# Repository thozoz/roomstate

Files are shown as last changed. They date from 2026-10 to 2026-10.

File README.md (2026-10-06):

# RoomState — ESP32-C3 Temperature/Humidity Monitor

A compact, battery-powered ambient temperature and humidity monitor featuring an ESP32-C3 Super Mini, DHT22 sensor, and a 0.96" SSD1306 OLED display. The monitor is housed in a custom two-part 3D-printed enclosure; build photos are shown below.

When operating on battery power, the ESP32-C3 enters light sleep between three-second sensor update cycles, allowing the OLED to retain its display buffer while reducing CPU consumption. Light sleep automatically disengages whenever a USB serial host is connected so uploading, monitoring, and debugging continue normally.

- **Board:** ESP32-C3 Super Mini (native USB-Serial/JTAG, **no** USB-UART bridge chip)
- **Sensor:** DHT22 (isolated thermal chamber)
- **Display:** 0.96" 128x64 OLED, SSD1306, I2C, address `0x3C`
- **Power & Charging:** 18650 Li-ion cell + TP4056 (with DW01A/8205A protection circuit) + KCD1 rocker switch
- **Enclosure:** Custom 3D-printed two-part desk enclosure (Bambu Lab P2S, PLA)
- **Framework:** PlatformIO + Arduino framework, flashed via esptool

---

## Physical Build & Enclosure Photos

### 1. Assembled Monitor

The assembled black enclosure with the OLED displaying temperature and humidity, the rocker switch, and the ventilation grille.

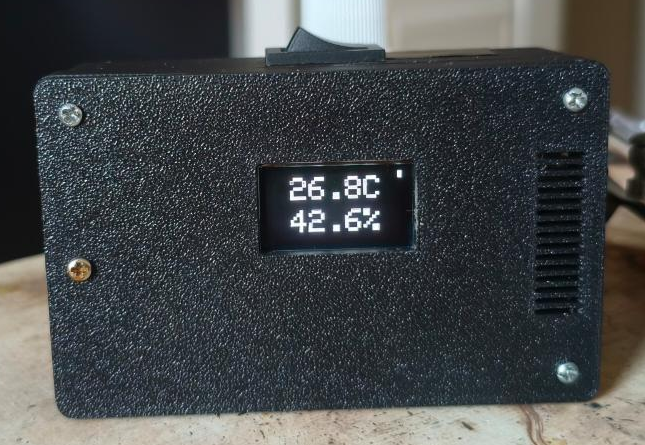
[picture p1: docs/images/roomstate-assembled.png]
Assembled RoomState monitor displaying temperature and humidity


### 2. Printed Lid

The lid before assembly, showing the OLED opening, ventilation slots, and screw holes.

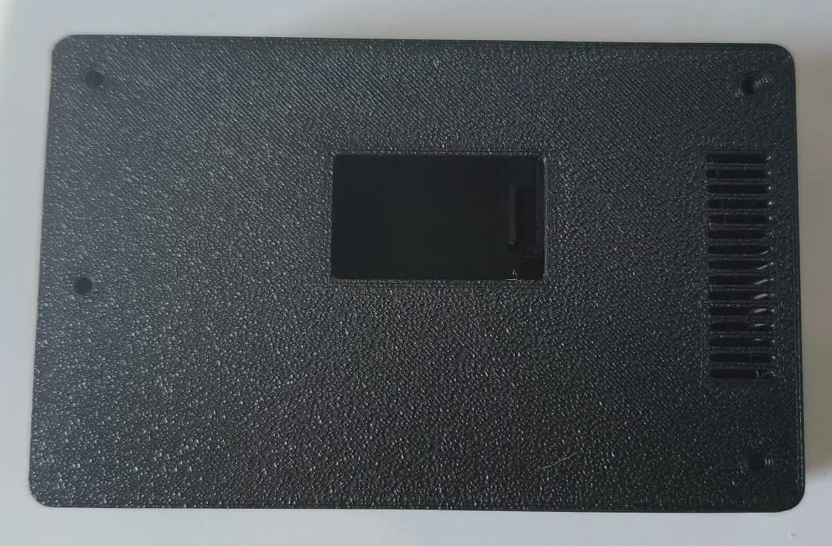
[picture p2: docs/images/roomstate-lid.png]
Black 3D-printed lid with OLED opening and ventilation slots


### 3. Base Interior

The empty base, showing the internal mounting features, compartment divider, and ventilation openings.

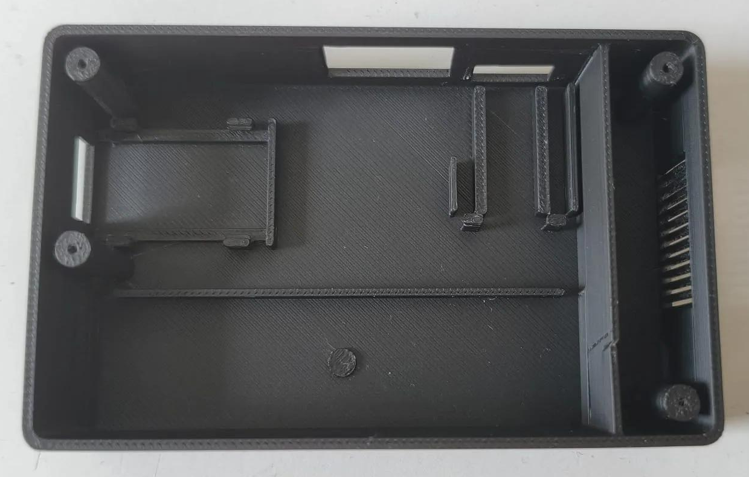
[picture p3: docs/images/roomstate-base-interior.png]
Empty 3D-printed base with mounting features and compartment divider


### 4. Internal Electronics — Angled View

The open enclosure showing the wiring, perfboard, and the OLED module mounted behind the lid.

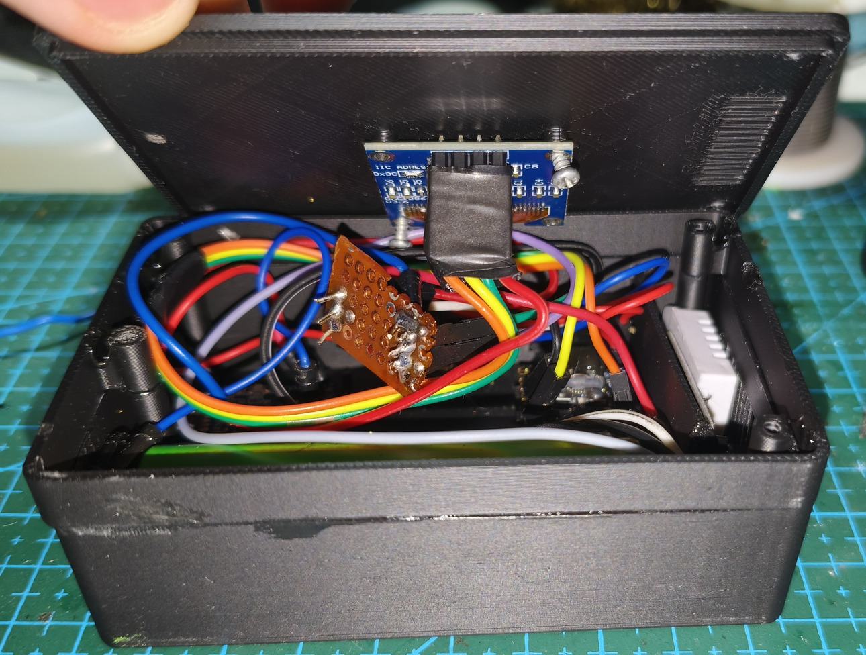
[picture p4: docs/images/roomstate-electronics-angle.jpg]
Angled view of the open RoomState enclosure, wiring, and lid-mounted OLED module


### 5. Internal Electronics — Overhead View

A closer overhead view of the 18650 cell, charging module, ESP32-C3, DHT22 sensor, and wiring.

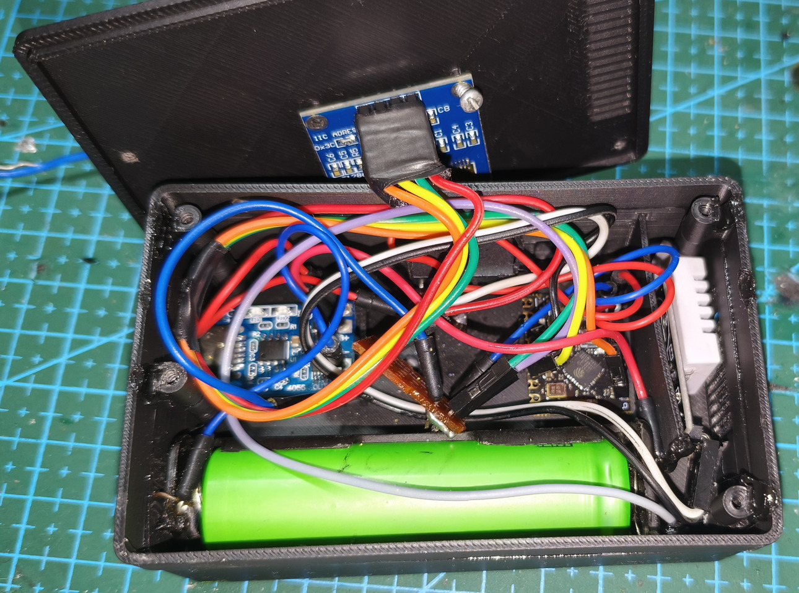
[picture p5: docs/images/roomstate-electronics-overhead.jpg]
Overhead view of the installed battery, charging module, ESP32-C3, DHT22 sensor, and wiring


---

## Pinout (Final, Verified)

| Component | ESP32-C3 Pin |
|---|---|
| DHT22 DATA | GPIO7 |
| OLED SDA | GPIO0 |
| OLED SCL | GPIO10 |
| OLED VCC / GND | **Directly from ESP 3.3V / GND** |
| DHT22 VCC / GND | **Directly from ESP 3.3V / GND** |

### Pins to Avoid

| Pin | Reason |
|---|---|
| GPIO2, GPIO8, GPIO9 | Strapping pins. If at an incorrect logic level during reset, the board will fail to boot. GPIO8 is also the onboard LED. |
| GPIO5 | Has internal board leakage on this module (behaves the same on a breadboard, internal to the ESP). |

---

## Critical Assembly Rule

> **Power modules directly from the ESP's 3.3V and GND pins, NOT from perfboard power rails.**

The longest troubleshooting session in this project stemmed from this. The display power was routed through perfboard tracks where the return ground path was inadequate. The multimeter read 3.29V at the VCC pad, yet the display was completely inoperable.

A voltmeter draws virtually no current — **it cannot detect a broken ground return path.** Voltage looks correct, yet the device is dead.

---

## Troubleshooting Guide

### Symptom → Cause Table

| Symptom | Meaning |
|---|---|
| `SDA` LOW, `SCL` clean HIGH | **Module is unpowered.** The line with a pull-up inside the module (DHT DATA, OLED SDA) gets pulled down to a dead VCC rail (~0.6V). SCL (without internal pull-up) stays clean HIGH via the ESP pull-up. This distinction is the most reliable clue. |
| Both lines LOW | Dead bus: wire shorted to GND, or a slave device is hung mid-transfer. |
| Lines clean HIGH, but no ACK | Signal is not reaching display (cold solder joint / broken wire), or SDA/SCL swapped. |
| Display freezes on last frame | ESP continues running but I2C writes fail. SSD1306 retains image in its internal GDDRAM. If the display had died completely, the screen would be blank. |
| `OLED init duration: 12003 ms` | 12 × 1000ms timeout. Bus completely dead. `display.begin()` still returns "true" — **it does not verify ACK**, do not trust its return value. |

### Software Pin Health Check

Drive the pin HIGH push-pull, then release it to internal pull-up (~45kΩ) only:

| Driven | Pull-up | Result |
|---|---|---|
| 1 | 1 | **Clean** |
| 1 | 0 | **Resistive leakage** (a few kΩ) — continuity buzzer stays silent, but pin fails to stay HIGH |
| 0 | 0 | **Hard short circuit** |

Timing is critical: after enabling pull-up, wait at least a few milliseconds. Sampling within microseconds reads LOW before the line has finished rising.

### Why Multimeters Can Mislead

- **Continuity buzzers only sound below ~50Ω.** A 6kΩ leakage pulls a logic pin LOW, but the buzzer stays silent. "No buzzer" does not mean no short.
- **Never perform continuity tests while powered.** Capacitors charging cause brief beeps, giving false positives.
- **TP4056 body diode.** Even when protection MOSFETs are off, current flows in one direction through the body diode (buzzer sounds) — yet there is no true operational ground path.
- **Voltmeters cannot see open grounds.** Correct voltage reads at VCC, but device still does not work.

### The TP4056 Grounding Trap

On protected TP4056 modules, MOSFETs sit **directly on the GND return path** (between B− and OUT−). **If no battery is connected, OUT− is disconnected.** If testing without a battery, do not establish common ground through the TP4056.

Proper wiring:
- TP4056 `B+` / `B−` → Battery
- TP4056 `OUT+` → ESP **5V** pin (never 3.3V pin — raw battery voltage reaches 4.2V)
- TP4056 `OUT−` → ESP GND
- Other modules' power → **ESP 3.3V / GND pins**, not TP4056

---

## Software Pitfalls

### 1. USB CDC Flags Are Required

The Super Mini lacks a dedicated USB-to-UART bridge chip. Without these flags, `Serial` outputs to physical UART0 pins (GPIO20/21) rather than the native USB port — you will not see a single line in terminal:

```ini
build_flags =
    -D ARDUINO_USB_MODE=1
    -D ARDUINO_USB_CDC_ON_BOOT=1
```

`ARDUINO_USB_CDC_ON_BOOT` defaults to 0. ESP32-C3 lacks full USB-OTG, only having USB-Serial/JTAG — correct mode is `ARDUINO_USB_MODE=1`.

### 2. `display.begin()` Does Not Verify ACK

It returns `true` even with no display connected, locking execution for ~12 seconds timing out on each command. Solution: verify device presence first via bit-bang probe before initializing.

### 3. Wire Peripheral Hangs on Faulty Bus

`Wire.setTimeOut()` does not cover every condition. If SCL cannot rise, `Wire.endTransmission()` can block indefinitely. Therefore:
- `Wire.begin()` is **never called** until the display is detected
- Device presence is verified via bit-bang I2C (deterministic timing, never blocks)

### 4. `Wire.end()` + `Wire.begin()` Loops Crash the Core

Do not call this pair repeatedly for periodic reconnection. Keep Wire uninitialized and use bit-bang probing instead.

### 5. Do Not Call `pinMode()` on I2C Pins While Wire Is Active

In arduino-esp32, this can break GPIO matrix routing and disconnect Wire entirely. Wire must be inactive during bit-bang operations.

### 6. 400 kHz Requires External Pull-ups

Adafruit_SSD1306 defaults bus speed to 400 kHz. Without external pull-ups, only the ESP's ~45kΩ internal pull-ups remain, and signal edges cannot rise fast enough. Reduce to 100 kHz:

```cpp
Adafruit_SSD1306 display(SCREEN_WIDTH, SCREEN_HEIGHT, &Wire, OLED_RESET, 100000UL, 100000UL);
```

Permanent solution: 4.7kΩ resistors from SDA and SCL to 3.3V. **However, if there is kΩ-range leakage on the line, even external pull-ups will not save it** — 6kΩ leakage with 4.7kΩ pull-up only reaches ~1.85V, well below the HIGH logic threshold.

### 7. Boot-time Serial Output Is Dropped

Data sent before the USB-CDC host connects is lost. Rather than printing diagnostics once in `setup()`, include recurring status lines inside `loop()`.

### 8. DTR/RTS When Connecting to Serial Port

- **DTR=1, RTS=0** → Normal read mode (HWCDC only sends output once host indicates connection)
- **DTR=1, RTS=1** → Board enters download mode and stays halted, producing no output

---

## Physical Assembly Notes

- Do not route signal and power through perfboard copper tracks. Run wires **directly to ESP pins**, using the perfboard purely as a mechanical carrier.
- Do not solder the ESP directly; **use pin headers** — if module replacement is needed, the entire board won't need rebuilding.
- **Use solid core wire.** A single stray strand from stranded wire reaching an adjacent pad is invisible, won't trigger continuity buzzers, yet causes a few kΩ of leakage.
- Clean after every solder operation with **isopropyl alcohol** (IPA, 90%+). Flux residue produces leakage in the exact kΩ range.
- **Avoid oxidant creams / hydrogen peroxide.** Creams leave conductive, hygroscopic films; peroxide oxidizes copper.
- Disconnect board power before swapping wires.
- Keep the ESP antenna keepout zone (opposite side of USB-C) clear of copper and wiring.

---

## Useful Commands

Find the device port with `pio device list`. Replace `COMx` below with your port (for example, `COM4` on Windows or `/dev/ttyACM0` on Linux). PlatformIO upload discovers the port automatically.

```bash
# Build and upload
pio run -t upload

# Reset chip (if stuck in download mode)
python -m esptool --port COMx --after hard-reset chip-id

# Full flash erase
python -m esptool --port COMx erase_flash
```

Reading serial output with PowerShell (more deterministic than `pio device monitor` — manual DTR/RTS control):

```powershell
$p = New-Object System.IO.Ports.SerialPort COMx,115200,None,8,one
$p.Open(); $p.DtrEnable=$true; $p.RtsEnable=$false
Start-Sleep -Milliseconds 5000
$p.ReadExisting(); $p.Close()
```

---

## Files

| Path | Description |
|---|---|
| `src/main.cpp` | Main firmware |
| `platformio.ini` | Board definition, USB CDC flags, libraries |
| `ENCLOSURE.md` | 3D-printed enclosure design and dimension specifications |
| `enclosure/` | 3D model exports (Base.stl, Lid.stl, STEP assemblies) |

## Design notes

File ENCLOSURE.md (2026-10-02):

# Enclosure Design

3D-printed two-part enclosure for RoomState (ESP32-C3 temperature/humidity monitor).
Modelled in Fusion 360 via the Fusion MCP server. This document tracks the design as it evolves;
sections marked **TBD** are filled in as components get measured.

## Print Target

- Printer: Bambu Lab P2S
- Material: PLA
- Goal: fast print, minimal plastic. No supports needed for either part.
- Clearance on all mating/seating surfaces: 0.15–0.2 mm

## Overall Structure

| Item | Value |
|---|---|
| Outer size | 93.2 × 58.2 × 25.6 mm |
| Inner cavity | 90 × 55 × 22 mm |
| Wall / floor | 1.6 mm (4 perimeters at 0.4 mm, no infill needed) |
| Lid | 2 mm plate + 1.5 mm inner lip, 0.2 mm clearance |
| Corners | outer R3, inner cavity R1.5, lid lip R1.3 |
| Fastening | 4 bosses, M2 self-tapping. Boss Ø5, pilot hole Ø1.6, lid through-hole Ø2.2 |
| Plastic | Base 22.2 cm³, Lid 10.4 cm³ (solid volume) |
| Orientation | Desk-clock style: screen faces up on the lid, USB-C and sensor grille on side walls |

Coordinate convention (used in all scripts): X = length, Y = width, Z = height. The inner cavity is fixed at X 2–92, Y 2–57, Z 2–24 and
every component position below is in these absolute coordinates; the outer shell is 1.6 mm outside that (0.4–93.6 / 0.4–58.6 / floor from 0.4). Units in Fusion API are cm; all scripts use a `MM = 0.1` helper.

The model is generated by Fusion API scripts (via the Fusion MCP server), not driven by user parameters. Changing a dimension means
editing the script values and regenerating the Base/Lid components; all component models (OLED, ESP32, DHT22 STEP files) stay in place.

## Internal Layout (top view, X left → right)

```
 X=0                                                   X=94
 +---------------------------------------------------------+
 |  DHT22    |                                    TP4056   |  <- Y high (back)
 |  compart- |  [ 18650 battery cradle, along X ]          |
 |  ment     |                                             |
 |  (grille  |                                             |
 |  on left  |   ESP32-C3         OLED (on lid,            |
 |  wall)    |   (floor)          window above)   USB-C -> |  <- Y low (front)
 +-----------+---------------------------------------------+
             ^ divider wall X=14
```

| Component | Position (mm, absolute) | Notes |
|---|---|---|
| DHT22 | PCB vertical at X 11.4–13, Y 22–50; sensor body Y 18–38 with mesh facing the X=0 wall | Own compartment, isolated from heat sources |
| Divider wall | X 14–15.2, full width, Z 2–22.3 (stops under the lid lip) | 8 × 6 mm cable notch at floor, Y 46–54 |
| ESP32-C3 SuperMini | On 3.5 mm rails, X 17–35, Y 2.5–25, USB-C toward the front wall | Headers pointing up |
| Rocker switch | Front wall, X 36–55.2 | Snap-in, body inside to Y 14 |
| OLED 0.96" | Mounted under the lid, board centre (45, 21), pins toward +Y | See OLED section |
| TP4056 USB-C | On 2 mm rails, X 64.5–91.5, Y 10–28 | Connector face recessed 1.1 mm inside the X=94 wall |
| 18650 in cut holder | Along X, holder X 16.5–91.5, Y 37–57 | Peg + rail + end stops, against the back wall |

Heat separation: TP4056 (charging heat) is ~55 mm from the DHT22, ESP32 ~16 mm, plus the divider.
Firmware runs WiFi/BLE off at 80 MHz so the ESP32 itself is negligible. Expect +1–2 °C drift on the
DHT22 while charging; mitigations under consideration: lid vents over TP4056, reading CHRG pin to
flag/offset readings, dropping charge current to 500 mA (R_PROG 1.2k → 2.4k).

## Cutouts and Features

### Base
- **DHT22 grille** (X=0 wall): 12 vertical slots, 0.9 mm wide, 1.9 mm pitch, Y 17–39, Z 3.2–17.3 — directly over the sensor mesh.
- **USB-C port, TP4056** (X=94 wall): 12.5 × 7.3 mm, Y 12.75–25.25, Z 3.7–11. Sized for the plug overmold (~12 × 6.5) since the receptacle face is recessed 1.1 mm.
- **USB-C port, ESP32 debug/programming** (Y=0 wall): 12.5 × 7.3 mm, X 19.75–32.25, Z 4.45–11.75. Same reasoning. Optional — can be left out of the print if not wanted.
- **Rocker switch cutout** (Y=0 wall): 19.2 × 13.2 mm, X 36–55.2, Z 6.4–19.6.
- **Board retention (snap-fit clips)**: vertical posts 1.2 mm thick outside the board edge, with a 0.6 × 0.8 mm hook overhanging the board top (+0.2 clearance). Press the board down, the post flexes, the hook holds it. No screws.
  - TP4056: 2 clips on each long edge (X 67–71 and 85–89, at Y 8.8 and 28), rear stop rib at X 63.3–64.5. Front is located by the USB-C in its cutout.
  - ESP32: long edges carry the headers, so clips sit on the rear edge (Y 25–26.2) at X 18–21 and 31–34, either side of the antenna. Side guides at X 15.9–17 (Y 3–24) and X 35–35.9 (Y 15–24, short to clear the rocker body). Front located by the USB-C.
- **Battery holder locating features**: Ø4.6 × 0.9 peg at (52.8, 47) (flush with the holder floor so the cell never touches it); rail X 18.3–87.3, Y 35.8–37, 5 mm tall; end stops X 14–15.3 (merged with the divider) and 90.3–92, 5 mm tall.
- **Screw bosses**: (6.2, 6.2), (87.8, 6.2), (6.2, 52.8), (87.8, 32). Three corners plus one mid-wall on the right (the corner spot is taken by the battery holder). Pilot hole 8 mm deep.

### Lid
- **OLED window**: 26 × 15.3 mm at X 32–58, Y 15.5–30.8 (4.2–19.5 mm below the pin edge). On this module the visible area starts right at the glass edge nearest the pins and runs 15 mm; the black flex zone is at the far end of the glass.
- **OLED bosses**: 4 × Ø3.8, 2 mm standoff, Ø1.5 pilot hole, at (33.5, 9.75), (56.5, 9.75), (33.5, 32.95), (56.5, 32.95).
- **Chimney vents** over DHT22 compartment: same slot pattern as the grille, X 4–12. Air enters via side grille, exits through lid.
- **Screw holes**: Ø2.2 through, at corner boss positions.

## Components

### OLED 0.96" SSD1306, 4-pin I2C, white — DONE (real STEP model)
Ruler measurements were inconsistent, so the component is now the community STEP model
`OLED_27x27.step` (KiCad library, github.com/louiscklaw/kicad_library), which matched every
measurement that could be trusted. Dimensions from the model, all "p" values measured from the pin edge:

| Dim | Value |
|---|---|
| Board | 27.3 × 27.3 mm, 1 mm thick |
| Mounting holes | 4 × Ø2.1 slots, centres 2.05 mm from the pin edge and from the far edge (Y spacing 23.2). In X the slots run 18.7–22.7 mm apart; **the actual board has round holes at the outer end**, so bosses sit 23.0 apart (first print had them at the slot middle, 20.7 — wrong, lid reprinted). |
| Glass | 27 × 19 × 1 mm, p = 4.15 … 23.15 |
| Visible / lit | visible area p ≈ 4.2 … 19.5 (starts at the pin-side glass edge, 15 mm long); flex/black zone p 19.5 … 23.15 |
| Pins | 4 × 2.54 header on the pin edge, pointing down (away from the glass), 9 mm long |

Placement: board centre X = 45, pin edge at Y = 35 (pins toward the battery side), board top at Z = 22, glass top at Z = 23 (1 mm below the lid underside).

### DHT22 breakout, 3-pin — DONE (measured + STEP sensor) — **sensor on hand is dead** (solder ball inside, reads 90–114 °C); replacement pending, same module type keeps the box unchanged. AHT20/SHT31 (I2C) would also fit and is the better sensor.
| Dim | Value |
|---|---|
| PCB | 28 × 13 × 1.6 mm, 3-pin header on one short edge |
| Sensor body | 15.1 × 20 × 7.7 mm (STEP `DHT22.stp`, TrailCurrent KiCad lib), plus 5.1 mm mounting tab at the far end → 25.2 total (measured 26) |
| Sensor position | body starts 12 mm from the pin edge, lies flat on the PCB, overhangs the far PCB edge by ~9 mm (total module length ~37) |
| Mesh area | ~20 × 14 mm on the face away from the PCB |

Placement: PCB stands vertical, parallel to the X=0 wall, at X 11.4–13, Y 22–50, Z 3.25–16.25.
Sensor body Y 18–38, Z 2.2–17.3, mesh face at X 3.7 (1.7 mm from the wall). Header at Y 50, pins toward +Y,
next to the cable notch. Module sits loose between wall and divider (2.7 mm play in X); no clips yet.

### TP4056 USB-C charger (with DW01A/8205A protection) — DONE (measured)
Two variants were available (27 × 18 and 19 × 15); the larger one is used — more copper, runs cooler, and there is room.

| Dim | Value |
|---|---|
| Board | 27 × 18 × 1.0 mm |
| USB-C | protrudes 1.4 mm past the board edge; total height board underside → connector top = 5 mm; receptacle ~9 × 3.3 |
| Pads | B+/B−/OUT+/OUT− on the edge opposite the USB-C |

Placement: board X 64.5–91.5, Y 10–28, on two 2 mm rails (Z 2–4) so the port cutout stays above the floor.
Board edge sits 0.5 mm back from the inner wall; USB-C face ends at X 92.9, i.e. 0.7 mm inside the outer surface (does not stick out).

### ESP32-C3 SuperMini — DONE (real STEP model)
STEP from github.com/mithro/esp32-to-433mhz (`esp32-c3-supermini.step`), matches the measured 18 × 22.5 board.

| Dim | Value |
|---|---|
| Board | 18 × 22.5 × 1.0 mm |
| USB-C | on a short edge, protrudes 1.5 mm, top at 4.2 mm above the board underside |
| Headers | 2 × 8 pins, 2.54 mm, along the long edges, **soldered pointing up** (decided). Pin stubs under the board ~2 mm → board sits on 3.5 mm rails. Pins top out at Z 11.6. |

Placement: board X 17–35, Y 2.5–25, board underside at Z 5.5 on two 3.5 mm rails at X 20–22 and 30–32 (inboard of the header rows). USB-C faces the front wall (Y=0),
face at Y 1.0 → 0.6 mm inside the outer surface (wall is now 1.6). (Moved 14 mm left from the first layout to make room for the rocker switch.) Pins used by firmware: GPIO7 (DHT data), GPIO0 (SDA), GPIO10 (SCL).

### 18650 Li-ion cell, 1200 mAh, in a cut-down spring holder — DONE (measured)
Cell Ø18 × 65 mm (the cell on hand is an 18650, not the 14500 first planned).
Runtime at ~35–40 mA (ESP32-C3 @ 80 MHz, WiFi off, OLED on, DHT22): ~30 h. Light-sleep between reads would stretch that to ~10 days — firmware task, later.

Holder: a 2×18650 spring holder cut down the middle to a single slot. One side keeps the holder's centre wall, the other side is open and rests against the box's back wall.

| Dim | Value |
|---|---|
| Holder (after cut) | 75 × 20 × 19 mm, ~1 mm floor |
| Floor hole | Ø5, centred (~38 mm from the end) |
| Solder tabs | at both ends — bend them inward/upward before fitting, there is no room past the holder ends |

Placement: X 15.3–90.3, Y 37–57 (open side to the back wall), Z 2–21. Held by: a Ø4.6 × 2.5 peg on the floor into the holder hole, a 1.2 mm rail along the inner side (Y 35.8–37, 5 mm tall), 5 mm end stops at X 15.3 and 91.5, and the back wall. No screws. Cell centre Y 47.5, Z 12; cell top Z 21.

Consequence: the back-right corner boss would collide with the holder, so it moved to (87.8, 32) — between the TP4056 and the holder. Lid hole pattern is asymmetric now.

### Power switch — DONE (KCD1 rocker, standard dims assumed)
Two options on hand: a KCD1-style rocker (~21 × 15 flange) and an SS12D00 mini slide. Rocker chosen: snap-in panel mount,
no screws or glue, works with a 2 mm wall. Rated 10 A, irrelevant at 40 mA.

| Dim | Value (standard KCD1-101, verify) |
|---|---|
| Flange | 21 × 15 mm, ~2 mm proud of the wall |
| Body behind flange | 19 × 13 mm, ~14 mm deep, then 2 pins ~6 mm |
| Panel cutout | 19.2 × 13.2 mm |

Location: front wall (Y=0), cutout X 36–55.2, Z 6.4–19.6 (centre X 45.6, Z 13). Body reaches inside to Y 14, pins to Y 20 — clear of the ESP32 (moved to X 17–35), TP4056 (X 64.5+) and the OLED (Z 21+).

## Wiring

Soldered connections (no Dupont — loosens inside a closed box). 24–26 AWG, 5–8 cm runs, heat-shrink on every joint.

| From | To |
|---|---|
| TP4056 OUT+ | rocker switch |
| rocker switch | ESP32 5V |
| TP4056 OUT− | ESP32 GND |
| TP4056 B+ / B− | holder tabs + / − |
| OLED VCC / GND / SDA / SCL | ESP32 3V3 / GND / GPIO0 / GPIO10 |
| DHT22 VCC / GND / DATA | ESP32 3V3 / GND / GPIO7 |

Note: TP4056 OUT is battery voltage (3.0–4.2 V) into the SuperMini 5V pin (regulator input). Works, but marginal at low charge.

**Backfeed / power switch:** the SuperMini's own USB-C connects VBUS straight to the 5V pin, so plugging the ESP32 USB while the battery is wired to the same pin would push 5 V back into TP4056 OUT+ and the cell. Solution chosen: a slide switch in series **TP4056 OUT+ → switch → ESP32 5V**. Switch off = battery fully disconnected from the ESP32, USB debug is safe, no diode needed. Charging via the TP4056 port works regardless of switch position (B+/B− path is not switched). Switch: KCD1 rocker on the front wall, right of the ESP32 USB-C.

## Open Decisions

- [ ] Verify the rocker switch flange/cutout against the actual part (19.2 × 13.2 assumed)
- [ ] Battery holder: confirm 75 × 20 × 19 and hole position after cutting
- [ ] Extra lid vents over TP4056 (only if charging drift turns out to matter)
- [ ] Firmware: light sleep to stretch battery life; optional CHRG-pin "charging" indicator

## Status

- [x] Box shell, lid, bosses, lip — 1.6 mm walls, R3 corners
- [x] OLED: real STEP model, window + bosses
- [x] DHT22: measured PCB + STEP sensor, side grille + lid chimney + divider
- [x] TP4056: measured, rails, USB-C cutout
- [x] ESP32-C3 SuperMini: real STEP model, headers up, rails, front USB-C cutout
- [x] 18650 in cut-down spring holder, peg/rail/stops
- [x] KCD1 rocker switch cutout, front wall
- [x] Snap-fit clips retain the TP4056 and ESP32 (no screws, no glue)
- [x] Interference check: 0 collisions between box, lid and all components
- [x] Exported: `enclosure/Base.stl` (as modelled), `enclosure/Lid.stl` (already flipped, flat face down — no rotation needed in the slicer), `enclosure/RoomState_enclosure.step` (full assembly incl. components)
- [ ] Print test fit (Base open side up, Lid top face down — no supports)
- [ ] Adjust after test fit

## Print Notes

- Base: print as modelled (open side up). Overhangs: USB-C/rocker cutouts are ≤ 19 mm bridges, fine for PLA.
- Lid: `Lid.stl` is exported already flipped — outer face on the bed, bosses and lip up. The OLED window and vent slots print as holes.
- 4 perimeters / 0.4 nozzle give solid 1.6 mm walls; 3–4 top/bottom layers; infill irrelevant.
- M2 × 6 self-tapping screws for the lid (4×) and the OLED (4×).

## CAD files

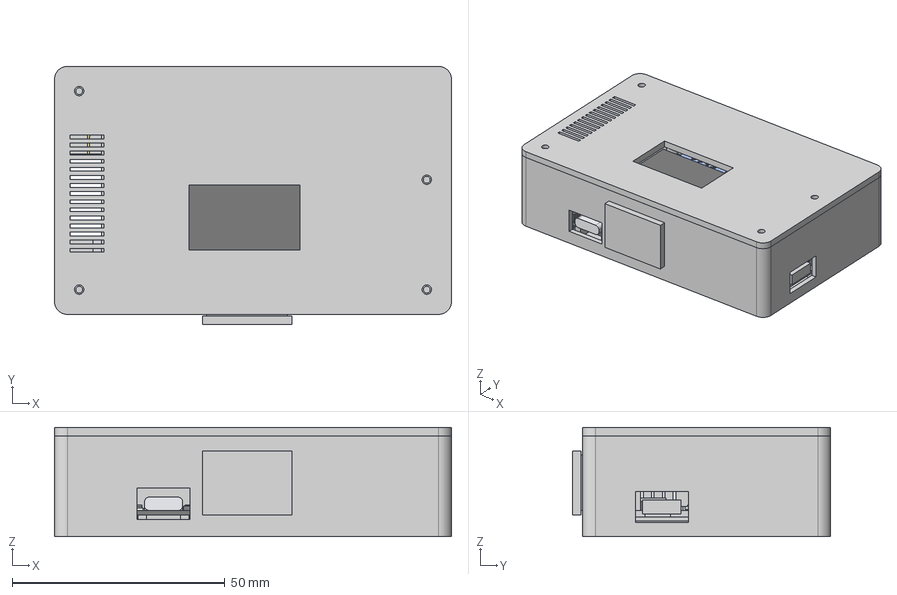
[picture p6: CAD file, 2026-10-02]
enclosure/RoomState_enclosure.step
93.2 x 60.6 x 25.6 mm
OLED_27x27
ОСНОВАНИЕ_DHT22
pcb_0
usb_c_1
button_2
button_cap_3
button_4
button_cap_5
esp32c3_6
crystal_7
ldo_8
led_9
led_10
antenna_11
pins_13
Lid

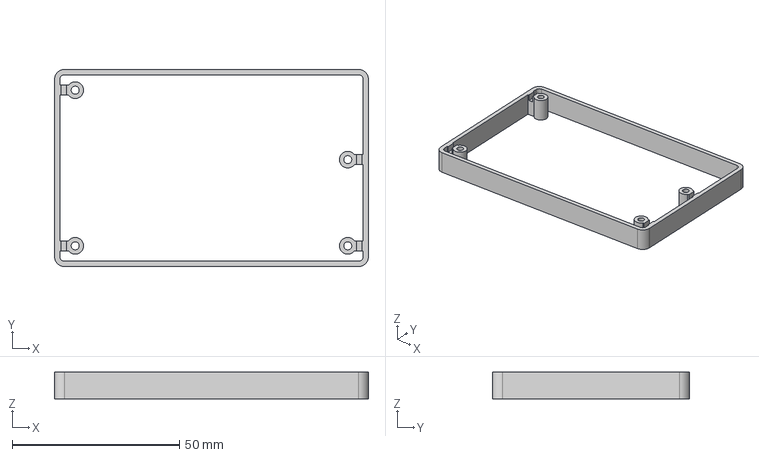
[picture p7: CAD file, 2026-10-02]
enclosure/Lid_Spacer_8mm.step
94.0 x 59.0 x 8.00 mm

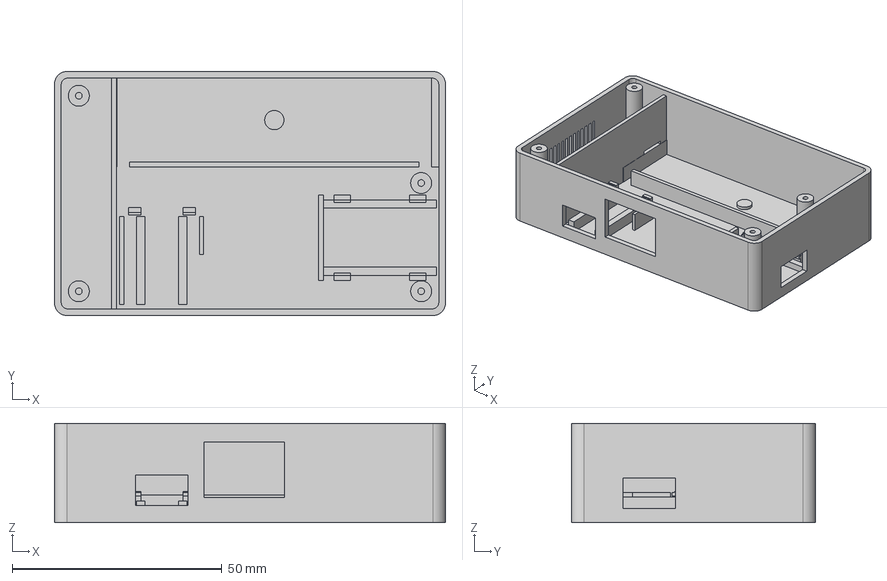
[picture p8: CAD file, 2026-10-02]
enclosure/Base.step
93.2 x 58.2 x 23.6 mm

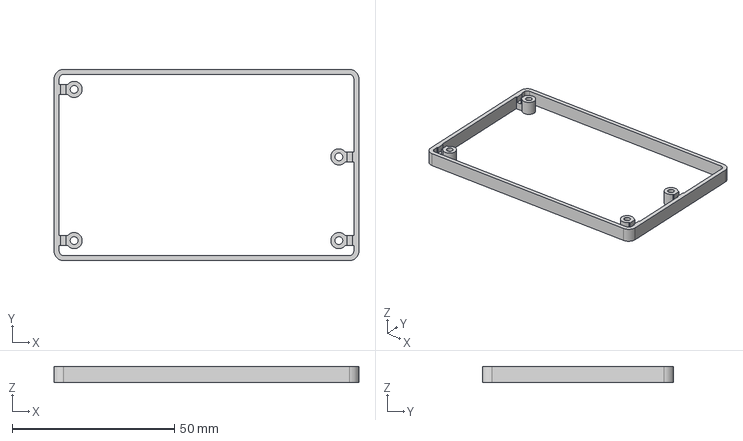
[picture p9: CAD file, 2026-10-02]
enclosure/Lid_Spacer_5mm.step
94.0 x 59.0 x 5.00 mm

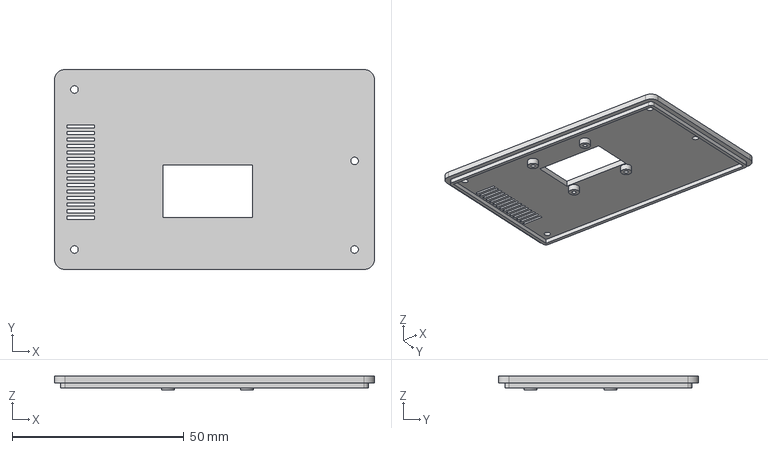
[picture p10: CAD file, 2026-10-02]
enclosure/Lid.step
93.2 x 58.2 x 4.00 mm

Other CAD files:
enclosure/Base.stl
enclosure/Lid.stl
enclosure/Lid_Spacer_5mm.stl
enclosure/Lid_Spacer_8mm.stl

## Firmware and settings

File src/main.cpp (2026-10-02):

#include <Arduino.h>
#include <Wire.h>
#include <DHT.h>
#include <Adafruit_GFX.h>
#include <Adafruit_SSD1306.h>
#include <esp_bt.h>
#include <esp_sleep.h>

// ---- Pin definitions (ESP32-C3 Super Mini) ----
// Strapping pins (GPIO2/8/9) are avoided. GPIO8 is also the onboard LED.
// GPIO5 has internal board leakage (even on a breadboard) - do not use.
#define DHT_PIN     7      // DHT22 data (module has internal pull-up)
#define DHT_TYPE    DHT22
#define I2C_SDA     0      // OLED SDA
#define I2C_SCL     10     // OLED SCL

// ---- OLED ----
#define SCREEN_WIDTH  128
#define SCREEN_HEIGHT 64
#define OLED_RESET    -1
#define OLED_ADDR     0x3C

// The last two parameters define I2C speed (during / after transfer). Library
// defaults to 400kHz; without external pull-up resistors (only ESP's ~45k weak internal
// pull-ups), the signal edges cannot rise in time at that speed. 100kHz leaves a safe margin.
Adafruit_SSD1306 display(SCREEN_WIDTH, SCREEN_HEIGHT, &Wire, OLED_RESET, 100000UL, 100000UL);

DHT dht(DHT_PIN, DHT_TYPE);

const unsigned long READ_INTERVAL_MS = 3000;   // DHT22 can be sampled at ~0.5Hz max
const unsigned long USB_DEBUG_GRACE_MS = 15000; // allow native USB time to enumerate after boot
unsigned long lastReadMillis = 0;

// Periodic retry if OLED is missing - allows the display to come online
// if a loose cable is reconnected without needing a board reboot.
const unsigned long OLED_RETRY_INTERVAL_MS = 5000;
unsigned long nextOledRetryMillis = 0;

float lastTemp = NAN;
float lastHum = NAN;
bool lastReadOk = false;
bool oledOk = false;

// ---------------------------------------------------------------------------
// Bit-bang I2C Probe
//
// display.begin() does not verify ACK: it returns "success" even with no display
// connected and locks up for ~12 seconds timing out on every command. Additionally,
// the ESP I2C peripheral can hang indefinitely on a faulty bus despite setTimeOut.
// Therefore, we probe "is the device present?" manually at the GPIO level -
// this routine never locks up under any circumstance.
// ---------------------------------------------------------------------------
#define BB_DELAY_US 5

static void bbRelease(uint8_t pin) { pinMode(pin, INPUT_PULLUP); }
static void bbPullLow(uint8_t pin) { pinMode(pin, OUTPUT); digitalWrite(pin, LOW); }

bool bitBangAck(uint8_t addr) {
    bbRelease(I2C_SDA); bbRelease(I2C_SCL); delayMicroseconds(50);
    if (!digitalRead(I2C_SDA) || !digitalRead(I2C_SCL)) return false;  // dead bus

    bbPullLow(I2C_SDA); delayMicroseconds(BB_DELAY_US);   // START
    bbPullLow(I2C_SCL); delayMicroseconds(BB_DELAY_US);

    uint8_t data = addr << 1;                             // address + write bit
    for (int i = 7; i >= 0; i--) {
        if (data & (1 << i)) bbRelease(I2C_SDA); else bbPullLow(I2C_SDA);
        delayMicroseconds(BB_DELAY_US);
        bbRelease(I2C_SCL); delayMicroseconds(BB_DELAY_US);
        bbPullLow(I2C_SCL); delayMicroseconds(BB_DELAY_US);
    }

    bbRelease(I2C_SDA); delayMicroseconds(BB_DELAY_US);   // ACK bit
    bbRelease(I2C_SCL); delayMicroseconds(BB_DELAY_US);
    bool ack = (digitalRead(I2C_SDA) == LOW);
    bbPullLow(I2C_SCL); delayMicroseconds(BB_DELAY_US);

    bbPullLow(I2C_SDA); delayMicroseconds(BB_DELAY_US);   // STOP
    bbRelease(I2C_SCL); delayMicroseconds(BB_DELAY_US);
    bbRelease(I2C_SDA); delayMicroseconds(BB_DELAY_US);
    return ack;
}

// Wire is never initialized until the display is actually found.
// This prevents peripheral operations on an empty bus and avoids Wire.end()/begin() loops.
bool tryInitOled() {
    bbRelease(I2C_SDA); bbRelease(I2C_SCL); delayMicroseconds(50);
    int sda = digitalRead(I2C_SDA);
    int scl = digitalRead(I2C_SCL);
    if (!sda || !scl) {
        Serial.printf("[I2C Bus Error] SDA=%d, SCL=%d (Line stuck LOW! Check loose wire or short)\n", sda, scl);
        return false;
    }
    if (!bitBangAck(OLED_ADDR)) {
        Serial.println("[I2C Probe] SDA & SCL HIGH, but device 0x3C gave no ACK (unpowered or wrong address)");
        return false;
    }

    Wire.begin(I2C_SDA, I2C_SCL);
    Wire.setClock(100000);
    Wire.setTimeOut(50);
    if (!display.begin(SSD1306_SWITCHCAPVCC, OLED_ADDR)) return false;
    display.setRotation(2);   // rotate display 180 degrees
    return true;
}

// Draws centered text horizontally at row y.
void drawCentered(const char* text, uint8_t size, int16_t y) {
    display.setTextSize(size);
    int16_t x1, y1;
    uint16_t w, h;
    display.getTextBounds(text, 0, 0, &x1, &y1, &w, &h);
    display.setCursor((SCREEN_WIDTH - w) / 2, y);
    display.print(text);
}

// Activity indicator: small bar moving down one step on each refresh along the right edge.
// Moves even when temp/humidity remain constant - if it stops, you know immediately
// that the display is frozen (e.g. I2C disconnected).
// Size 3 text at widest ("-10.5C", 6 chars = 108px) centered leaves ~10px padding on each side,
// bar at x=125..127 never overlaps text.
#define HEARTBEAT_STEPS 8
uint8_t heartbeatFrame = 0;

static void drawHeartbeat() {
    int16_t y = (heartbeatFrame % HEARTBEAT_STEPS) * (SCREEN_HEIGHT / HEARTBEAT_STEPS);
    display.fillRect(125, y, 3, 6, SSD1306_WHITE);
    heartbeatFrame++;
}

// Screen layout (128x64): temperature and humidity centered full screen
void drawReadings(float temp, float hum, bool ok) {
    if (!oledOk) return;
    display.clearDisplay();
    display.setTextColor(SSD1306_WHITE);

    if (!ok) {
        drawCentered("DHT22", 2, 16);
        drawCentered("ERROR!", 2, 36);
    } else {
        char tempStr[8];
        snprintf(tempStr, sizeof(tempStr), "%.1fC", temp);
        char humStr[8];
        snprintf(humStr, sizeof(humStr), "%.1f%%", hum);
        drawCentered(tempStr, 3, 4);
        drawCentered(humStr, 3, 36);
    }

    drawHeartbeat();
    display.display();
}

void setup() {
    Serial.begin(115200);
    Serial.println("=== Boot started ===");

    // Disable BLE to save battery
    btStop();
    esp_bt_controller_disable();

    setCpuFrequencyMhz(80);   // ESP32-C3: 80/40/20/10 MHz options

    // Wire is not initialized here - tryInitOled() initializes it if the display is found.
    oledOk = tryInitOled();
    Serial.printf("OLED: %s\n", oledOk ? "FOUND" : "NOT FOUND");
    if (oledOk) {
        display.clearDisplay();
        display.setTextColor(SSD1306_WHITE);
        display.setTextSize(1);
        display.setCursor(0, 0);
        display.println("Starting...");
        display.display();
    }

    delay(1500);   // DHT22 needs ~1 s after board power-up before the first read
    dht.begin();
}

void loop() {
    unsigned long now = millis();

    if (!oledOk && (long)(now - nextOledRetryMillis) >= 0) {
        nextOledRetryMillis = now + OLED_RETRY_INTERVAL_MS;
        if (tryInitOled()) {
            oledOk = true;
            Serial.println("OLED found later, display active.");
        }
    }

    if (now - lastReadMillis >= READ_INTERVAL_MS) {
        lastReadMillis = now;

        float h = dht.readHumidity();
        float t = dht.readTemperature();

        Serial.printf("[status] OLED: %-9s | ", oledOk ? "OK" : "NOT FOUND");
        if (isnan(h) || isnan(t)) {
            lastReadOk = false;
            Serial.println("DHT22 read error (NaN)");
        } else {
            lastReadOk = true;
            lastTemp = t;
            lastHum = h;
            Serial.printf("Temperature: %.1f C  Humidity: %.1f %%\n", t, h);
        }

        drawReadings(lastTemp, lastHum, lastReadOk);
    }

    // On battery, sleep until the next scheduled sensor read or OLED retry.
    // The SSD1306 retains its current image while the ESP32-C3 is asleep.
    // Keep the CPU awake while a USB serial host is connected for reliable debugging.
    if (millis() >= USB_DEBUG_GRACE_MS && !Serial) {
        now = millis();
        unsigned long untilRead = (now - lastReadMillis >= READ_INTERVAL_MS)
            ? 1
            : READ_INTERVAL_MS - (now - lastReadMillis);
        unsigned long sleepMs = untilRead;

        if (!oledOk) {
            long untilRetry = (long)(nextOledRetryMillis - now);
            unsigned long retryMs = untilRetry <= 0 ? 1 : (unsigned long)untilRetry;
            if (retryMs < sleepMs) sleepMs = retryMs;
        }

        esp_sleep_enable_timer_wakeup((uint64_t)sleepMs * 1000ULL);
        esp_light_sleep_start();
    }
}

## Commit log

2026-09-13 ESP32-C3 temperature/humidity monitor: firmware + diagnostic notes
    Live temperature and humidity display with DHT22 and SSD1306 OLED.
    Pin map: DHT22 -> GPIO1, OLED SDA -> GPIO6, SCL -> GPIO7.
    Firmware:
    - No 12-second lockup without display; device presence verified first
    via bit-bang I2C (display.begin() does not verify ACK)
    - Wire is never initialized until display is detected, preventing bus hang
    - Periodic retry every 5 seconds if display is absent
    - I2C at 100 kHz (no external pull-up, 400 kHz edge does not rise in time)
    - WiFi/BLE disabled, CPU at 80 MHz for power saving
    - WiFi/NTP clock feature disabled via ENABLE_WIFI_CLOCK flag
    README: symptom-cause diagnostic table, multimeter p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
    [main.cpp]
2026-09-13 feat(i2c): add detailed bus diagnostic logs to tryInitOled
    - Check and log SDA/SCL line states before probing OLED
    - Distinguish between shorted/stuck lines and unpowered/missing ACK
    [main.cpp]
2026-10-02 feat: add RoomState enclosure CAD and print files
    [Base.step, Base.stl, Lid.step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]
2026-10-05 docs: add enclosure photos and reserve electronics photo slot
2026-10-14 docs: tighten README claims to match what was actually verified
    - hedge GPIO5, rail, TP4056 and flux explanations (root cause not isolated)
    - mark 12 s display.begin() stall as historical (1000 ms timeout build)
    - add worked pull-up divider example (6k leak vs 4.7k -> ~1.85 V)
2026-10-16 docs: define firmware and enclosure licensing
